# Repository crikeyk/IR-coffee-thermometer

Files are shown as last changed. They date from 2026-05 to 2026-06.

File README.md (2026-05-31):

# IR-coffee-thermometer







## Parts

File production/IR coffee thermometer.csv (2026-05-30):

Reference | Qty | Value | DNP | Exclude from BOM | Exclude from Board | Footprint | LCSC
AE2 | 1 | Antenna_Chip |  |  |  | Capacitor_SMD:C_1206_3216Metric | C127629
C1,C3,C4,C5 | 4 | 10uF |  |  |  | PCM_JLCPCB:C_0603 | C96446
C2 | 1 | 1uF |  |  |  | PCM_JLCPCB:C_0402 | C52923
C6,C15,C19,C20,C21,C22 | 6 | 100nF |  |  |  | PCM_JLCPCB:C_0402 | C1525
C10,C11 | 2 | 12pF |  |  |  | PCM_JLCPCB:C_0402 | C1547
D1 | 1 | Green |  |  |  | PCM_JLCPCB:D_0805 | C2297
D2 | 1 | Red |  |  |  | PCM_JLCPCB:D_0805 | C84256
D3 | 1 | 1N4001W |  |  |  | PCM_JLCPCB:D_SOD-123FL | C18199085
FB1 | 1 |  |  |  |  | PCM_JLCPCB:FB_0805 | C1015
J2 | 1 | USB_C_Receptacle_USB2.0_16P |  |  |  | MyLib:USB_C_Receptacle_HRO_TYPE-C-31-M-12 | C165948
Q2 | 1 | HL2305 |  |  |  | PCM_JLCPCB:Q_SOT-23 | C28646261
Q3 | 1 | HJ8205 |  |  |  | PCM_JLCPCB:SOT-23-6_L2.9-W1.6-P0.95-LS2.8-BR | C20069150
R1 | 1 | 510Ω |  |  |  | PCM_JLCPCB:R_0402 | C25123
R2,R16,R17 | 3 | 22Ω |  |  |  | PCM_JLCPCB:R_0402 | C25092
R3,R4 | 2 | 4.7kΩ |  |  |  | PCM_JLCPCB:R_0402 | C25900
R5,R8,R11,R12,R13,R23,R24 | 7 | 10kΩ |  |  |  | PCM_JLCPCB:R_0402 | C25744
R6 | 1 | 330Ω |  |  |  | PCM_JLCPCB:R_0402 | C25104
R7 | 1 | 2kΩ |  |  |  | PCM_JLCPCB:R_0402 | C4109
R9 | 1 | 0Ω | DNP |  |  | PCM_JLCPCB:R_0402 | C17168
R10 | 1 | 1kΩ |  |  |  | PCM_JLCPCB:R_0402 | C11702
R14,R15 | 2 | 5.1kΩ |  |  |  | PCM_JLCPCB:R_0402 | C25905
R18,R19,R20 | 3 | 0Ω |  |  |  | PCM_JLCPCB:R_0402 | C17168
R21,R22 | 2 | 470Ω |  |  |  | PCM_JLCPCB:R_0402 | C25117
U1 | 1 | ESP32-C3FH4 |  |  |  | PCM_JLCPCB:QFN-32-1EP_5x5mm_P0.5mm_EP3.7x3.7mm_ThermalVias | C2858491
U3 | 1 | DW01A |  |  |  | Package_TO_SOT_SMD:SOT-23-6 | C18164398
U4 | 1 | TP4057 |  |  |  | PCM_JLCPCB:SOT-23-6_L2.9-W1.6-P0.95-LS2.8-BL | C12044
U5 | 1 | MCP1700x-330xxTT |  |  |  | Package_TO_SOT_SMD:SOT-23 | C39051
X1 | 1 | 40MHz, 15pF |  |  |  | PCM_JLCPCB:OSC-SMD_4P-L3.2-W2.5-BL_SIT8008BI | C9010

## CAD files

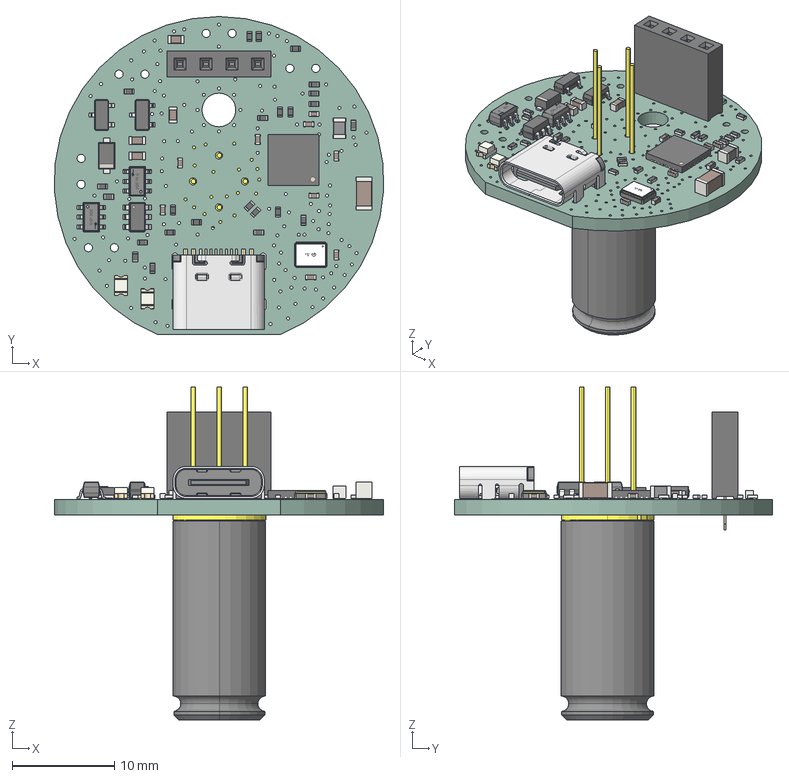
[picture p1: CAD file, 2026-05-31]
IR_coffee_thermometer_no_screen.step
32.3 x 31.2 x 32.6 mm
D_SOD_123F
LED_0805_2012Metric_Castellated x 2
R_0402_1005Metric x 24
C_0402_1005Metric x 9
SOT-23-6
C_0603_1608Metric x 4
PinSocket_1x04_P2.54mm_Vertical
C_1206_3216Metric
L_0805_2012Metric
SOT-23-6_L2.9-W1.6-H1.5-LS2.8-P0.95 x 2
OSC-SMD_4P-L3.2-W2.5-CJ13-320001210A20
ConPins
PcbPins
Mold
Frame
SOT-23
QFN-32-1EP_5x5mm_Pitch0.5mm
SOT_23
MLX90614xCI
IR coffee thermometer_PCB

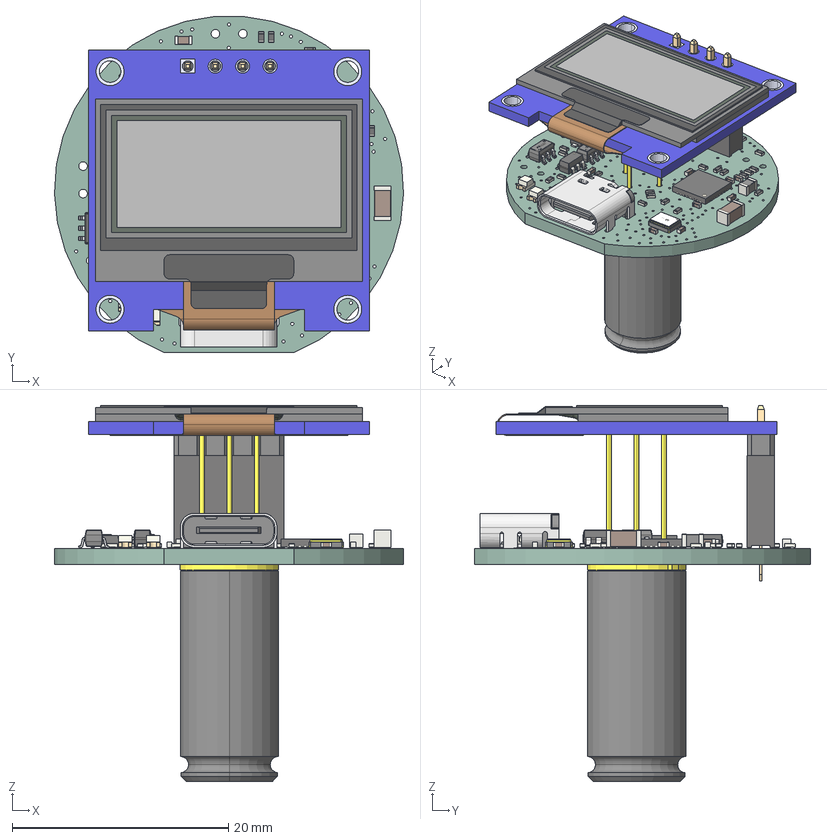
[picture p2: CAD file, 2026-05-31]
IR_coffee_thermometer.step
32.3 x 31.1 x 34.8 mm
D_SOD_123F
LED_0805_2012Metric_Castellated x 2
R_0402_1005Metric x 24
C_0402_1005Metric x 9
SOT-23-6
C_0603_1608Metric x 4
PinSocket_1x04_P2.54mm_Vertical
C_1206_3216Metric
L_0805_2012Metric
SOT-23-6_L2.9-W1.6-H1.5-LS2.8-P0.95 x 2
OSC-SMD_4P-L3.2-W2.5-CJ13-320001210A20
ConPins
PcbPins
Mold
Frame
DM-OLED096-636_Module
DM-OLED096-636_Panel
SOT-23
QFN-32-1EP_5x5mm_Pitch0.5mm
SOT_23
MLX90614xCI
IR coffee thermometer_PCB

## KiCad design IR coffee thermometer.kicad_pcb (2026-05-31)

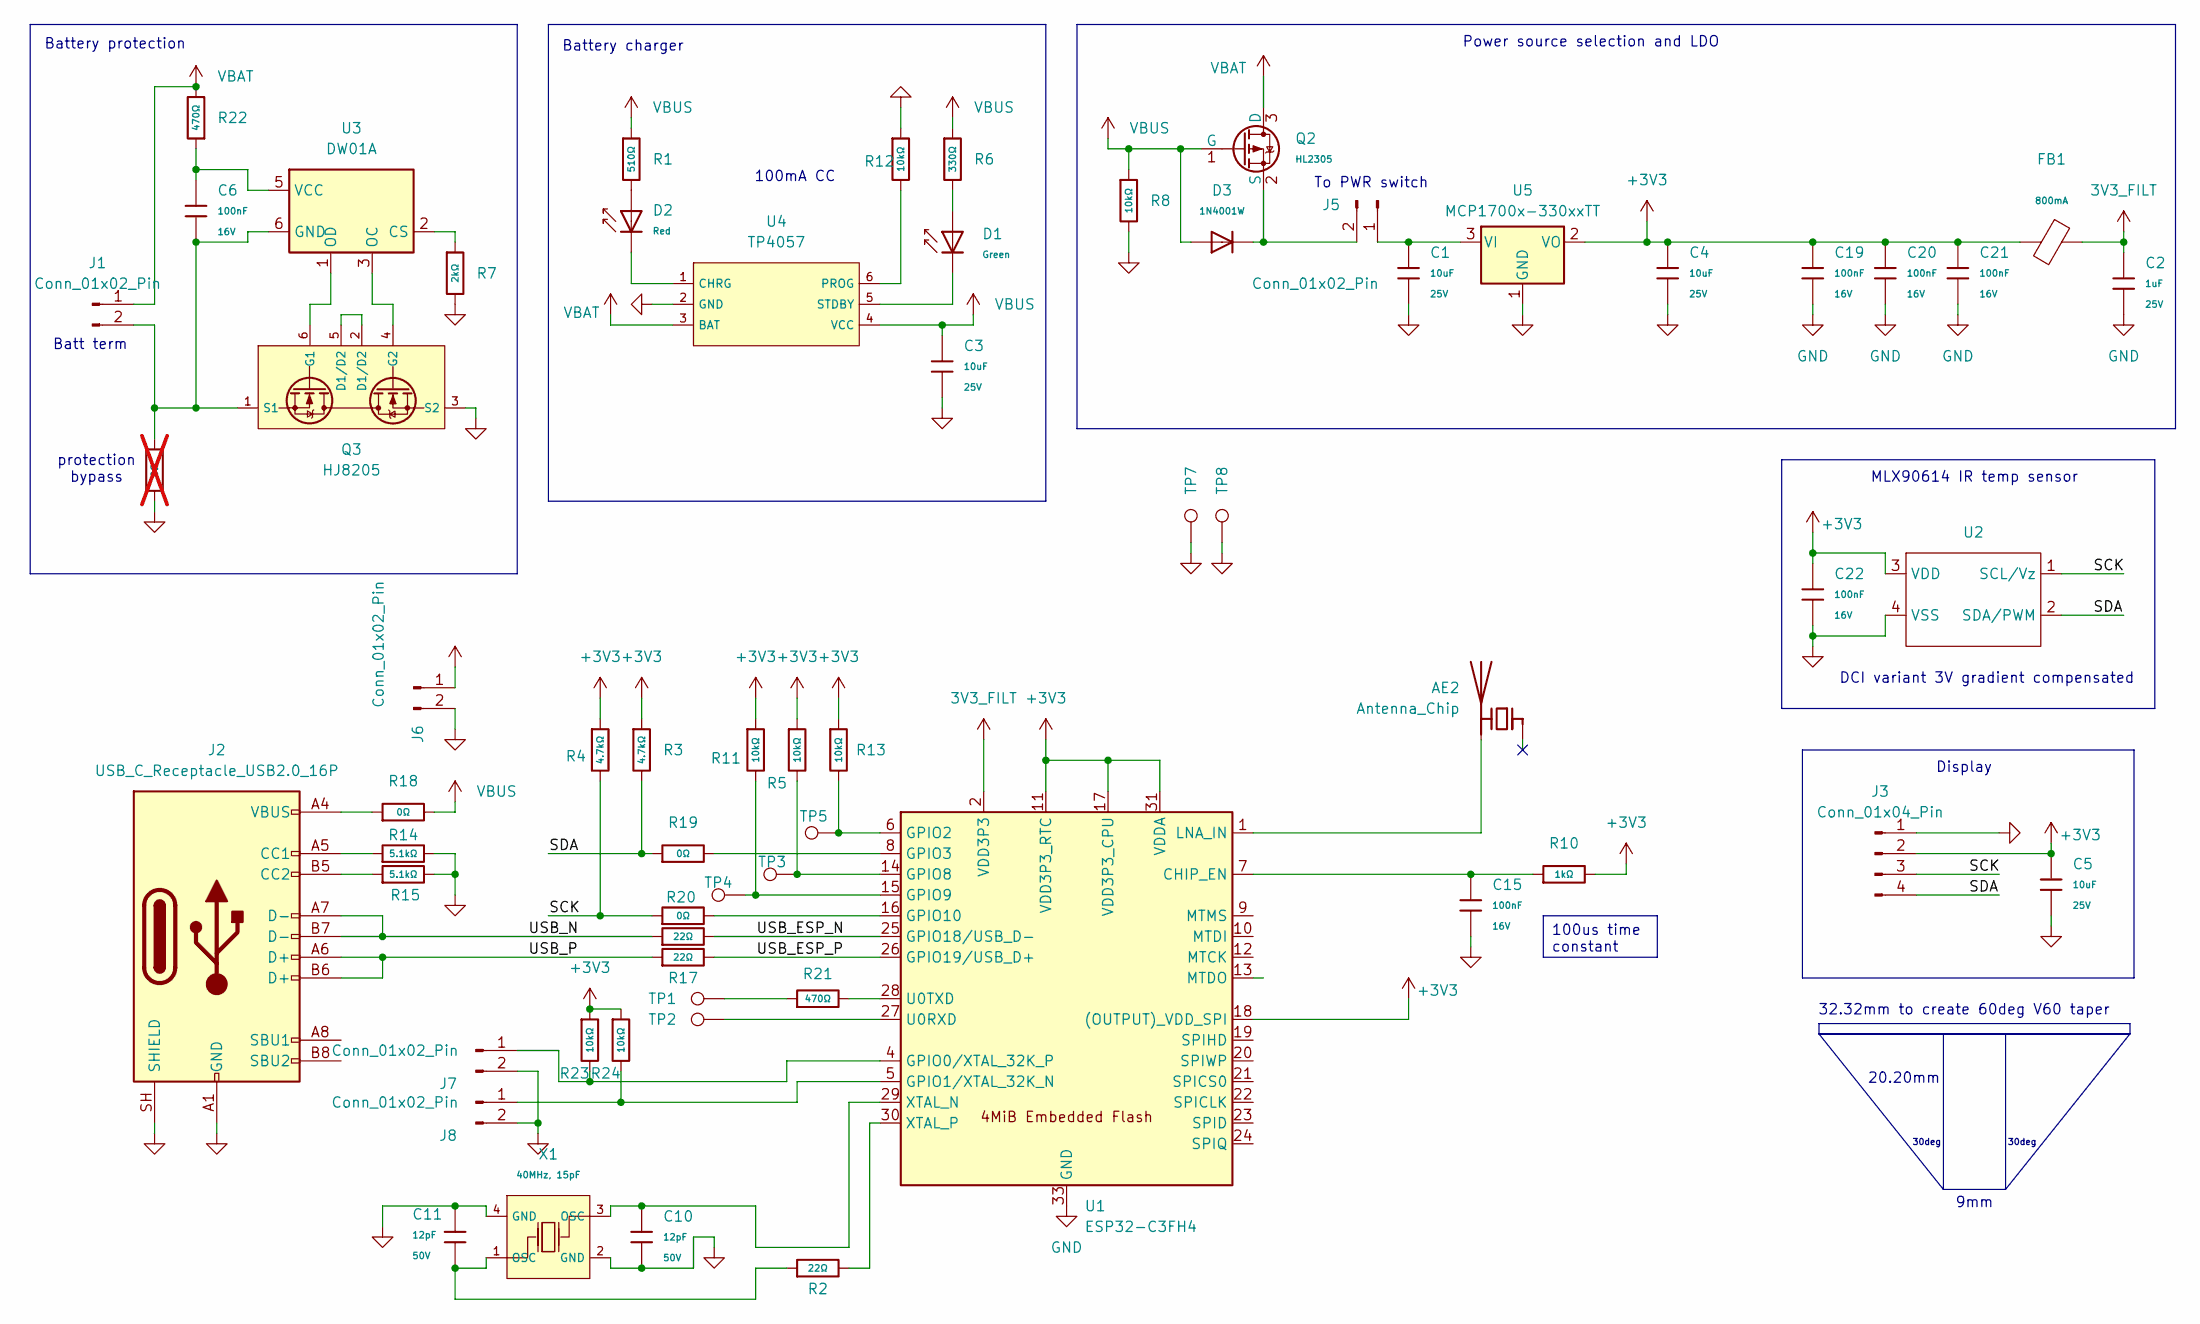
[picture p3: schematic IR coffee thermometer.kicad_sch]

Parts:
AE2: Antenna_Chip; C_1206_3216Metric; LCSC C127629
C1, C3, C4, C5: 10uF; C_0603; Voltage Rated 25V; Tolerance ±20%; Part CL10A106MA8NRNC; LCSC C96446
C2: 1uF; C_0402; Voltage Rated 25V; Tolerance ±10%; Part CL05A105KA5NQNC; LCSC C52923
C6, C15, C19, C20, C21, C22: 100nF; C_0402; Voltage Rated 16V; Tolerance ±10%; Part CL05B104KO5NNNC; LCSC C1525
C10, C11: 12pF; C_0402; Voltage Rated 50V; Tolerance ±5%; Part 0402CG120J500NT; LCSC C1547
D1: Green; D_0805; Part KT-0805G; LCSC C2297
D2: Red; D_0805; Forward Voltage (VF) 1.6V~2.6V; Part NCD0805R1; LCSC C84256
D3: 1N4001W; D_SOD-123FL; Voltage - Forward(Vf@If) 1V@1.0A; Voltage - DC Reverse(Vr) 50V; Part 1N4001W; LCSC C18199085
FB1: FB_0805; Current Rating 800mA; Tolerance ±25%; Part GZ2012D101TF; LCSC C1015
J1, J5, J6, J7, J8: Conn_01x02_Pin; TestPoint_2Pads_Pitch2.54mm_Drill0.8mm
J2: USB_C_Receptacle_USB2.0_16P; USB_C_Receptacle_HRO_TYPE-C-31-M-12; LCSC C165948
J3: Conn_01x04_Pin; PinSocket_1x04_P2.54mm_Vertical; LCSC C2718488
Q2: HL2305; Q_SOT-23; Part HL2305; LCSC C28646261
Q3: HJ8205; SOT-23-6_L2.9-W1.6-P0.95-LS2.8-BR; Part HJ8205; LCSC C20069150
R1: 510Ω; R_0402; Overload Voltage (Max) 50V; Tolerance ±1%; Part 0402WGF5100TCE; LCSC C25123
R2, R16, R17: 22Ω; R_0402; Overload Voltage (Max) 50V; Tolerance ±1%; Part 0402WGF220JTCE; LCSC C25092
R3, R4: 4.7kΩ; R_0402; Overload Voltage (Max) 50V; Tolerance ±1%; Part 0402WGF4701TCE; LCSC C25900
R5, R8, R11, R12, R13, R23, R24: 10kΩ; R_0402; Overload Voltage (Max) 50V; Tolerance ±1%; Part 0402WGF1002TCE; LCSC C25744
R6: 330Ω; R_0402; Overload Voltage (Max) 50V; Tolerance ±1%; Part 0402WGF3300TCE; LCSC C25104
R7: 2kΩ; R_0402; Overload Voltage (Max) 50V; Tolerance ±1%; Part 0402WGF2001TCE; LCSC C4109
R9: 0Ω; R_0402; Overload Voltage (Max) 50V; Tolerance ±1%; Part 0402WGF0000TCE; LCSC C17168; not fitted
R10: 1kΩ; R_0402; Overload Voltage (Max) 50V; Tolerance ±1%; Part 0402WGF1001TCE; LCSC C11702
R14, R15: 5.1kΩ; R_0402; Overload Voltage (Max) 50V; Tolerance ±1%; Part 0402WGF5101TCE; LCSC C25905
R18, R19, R20: 0Ω; R_0402; Overload Voltage (Max) 50V; Tolerance ±1%; Part 0402WGF0000TCE; LCSC C17168
R21, R22: 470Ω; R_0402; Overload Voltage (Max) 50V; Tolerance ±1%; Part 0402WGF4700TCE; LCSC C25117
TP1, TP2, TP3, TP4, TP5, TP7, TP8: TestPoint; TestPoint_Pad_D1.0mm
U1: ESP32-C3FH4; QFN-32-1EP_5x5mm_P0.5mm_EP3.7x3.7mm_ThermalVias; LCSC C2858491
U2: MLX90614
U3: DW01A; SOT-23-6; LCSC C18164398
U4: TP4057; SOT-23-6_L2.9-W1.6-P0.95-LS2.8-BL; Part TP4057-42-SOT26-R; LCSC C12044
U5: MCP1700x-330xxTT; SOT-23; LCSC C39051
X1: 40MHz, 15pF; OSC-SMD_4P-L3.2-W2.5-BL_SIT8008BI; PartID X322540MPB4SI; LCSC C9010

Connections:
3V3_FILT: C2.1, FB1.1, U1.2 (VDD3P3), U1.3 (VDD3P3)
+3V3: C4.1, C5.1, C19.1, C20.1, C21.1, C22.1, FB1.2, J3.2, R3.1, R4.1, R5.1, R10.2, R11.1, R13.1, R23.1, R24.1, U1.11 (VDD3P3_RTC), U1.17 (VDD3P3_CPU), U1.18 ((OUTPUT)_VDD_SPI), U1.31 (VDDA), U1.32 (VDDA), U2.3 (VDD), U5.2 (VO)
/SCK: J3.3, R4.2, R20.1, U2.1 (SCL/Vz)
/SDA: J3.4, R3.2, R19.1, U2.2 (SDA/PWM)
/USB_ESP_N: R16.2, U1.25 (GPIO18/USB_D-)
/USB_ESP_P: R17.2, U1.26 (GPIO19/USB_D+)
/USB_N: J2.A7 (D-), J2.B7 (D-), R16.1
/USB_P: J2.A6 (D+), J2.B6 (D+), R17.1
GND: C1.2, C2.2, C3.2, C4.2, C5.2, C10.2, C11.2, C15.2, C19.2, C20.2, C21.2, C22.2, J2.A1 (GND), J2.A12 (GND), J2.B1 (GND), J2.B12 (GND), J2.SH (SHIELD), J3.1, J6.2, J7.2, J8.2, Q3.3 (S2), R7.2, R8.2, R9.2, R12.1, R14.2, R15.2, TP7.1 (1_1), TP8.1 (1_1), U1.33 (GND), U2.4 (VSS), U4.2 (GND), U5.1 (GND), X1.2 (GND), X1.4 (GND)
unnamed: AE2.2 (PCB_Trace_2), U1.1 (LNA_IN)
unnamed: C11.1, R2.1, X1.1 (OSC)
unnamed: D1.2, R6.2
unnamed: D2.2, R1.2
unnamed: C6.2, J1.2, Q3.1 (S1), R9.1, U3.6 (GND)
unnamed: J2.A5 (CC1), R14.1
unnamed: J2.B5 (CC2), R15.1
unnamed: J2.A4 (VBUS), J2.A9 (VBUS), J2.B4 (VBUS), J2.B9 (VBUS), R18.1
unnamed: C1.1, J5.1, U5.3 (VI)
unnamed: D3.1, J5.2, Q2.2 (S)
unnamed: J7.1, R23.2, U1.4 (GPIO0/XTAL_32K_P)
unnamed: J8.1, R24.2, U1.5 (GPIO1/XTAL_32K_N)
unnamed: Q3.2 (D1/D2), Q3.5 (D1/D2)
unnamed: Q3.6 (G1), U3.1 (OD)
unnamed: Q3.4 (G2), U3.3 (OC)
unnamed: R21.1, TP1.1 (1_1)
unnamed: C15.1, R10.1, U1.7 (CHIP_EN)
unnamed 26: R13.2, TP5.1, U1.6 (GPIO2); also elsewhere on the board
unnamed: R19.2, U1.8 (GPIO3)
unnamed 28: R5.2, TP3.1, U1.14 (GPIO8); also elsewhere on the board
unnamed 29: R11.2, TP4.1, U1.15 (GPIO9); also elsewhere on the board
unnamed: R20.2, U1.16 (GPIO10)
unnamed: TP2.1 (1_1), U1.27 (U0RXD)
unnamed: R21.2, U1.28 (U0TXD)
unnamed: C10.1, U1.29 (XTAL_N), X1.3 (OSC)
unnamed: R2.2, U1.30 (XTAL_P)
unnamed: R7.1, U3.2 (CS)
unnamed: C6.1, R22.1, U3.5 (VCC)
unnamed: D2.1, U4.1 (CHRG)
unnamed: R12.2, U4.6 (PROG)
unnamed: D1.1, U4.5 (STDBY)
VBAT: J1.1, Q2.3 (D), R22.2, U4.3 (BAT)
VBUS: C3.1, D3.2, J6.1, Q2.1 (G), R1.1, R6.1, R8.1, R18.2, U4.4 (VCC)

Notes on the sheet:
30deg
DCI variant 3V gradient compensated
9mm
20.20mm
Power source selection and LDO
To PWR switch
100mA CC
Display
MLX90614 IR temp sensor
32.32mm to create 60deg V60 taper
Battery charger
protection bypass
Batt term
Battery protection
100us time constant

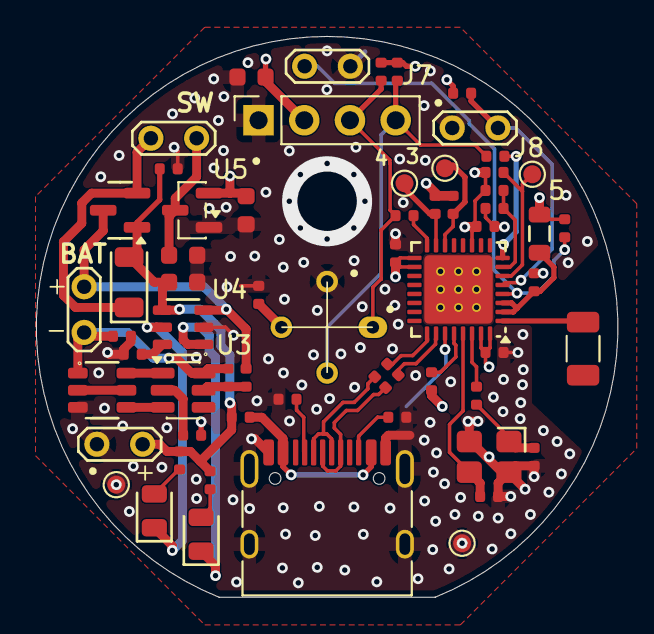
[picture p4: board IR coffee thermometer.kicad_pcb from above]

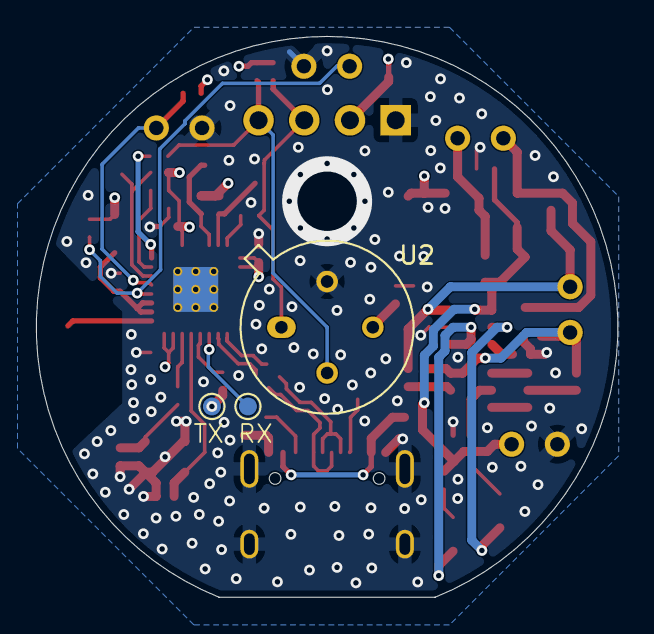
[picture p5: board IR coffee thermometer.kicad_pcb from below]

Board: 4 copper layers, 32.3 x 31.2 mm, 64 parts (3 on the bottom side), 42 nets.

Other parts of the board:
3, 4, 5: TestPoint; TestPoint_Pad_D1.0mm

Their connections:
unnamed 26: 5.1 (1_1); also elsewhere on the board
unnamed 28: 3.1 (1_1); also elsewhere on the board
unnamed 29: 4.1 (1_1); also elsewhere on the board

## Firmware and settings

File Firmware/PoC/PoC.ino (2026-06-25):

#include <Wire.h>
#include <Adafruit_GFX.h>
#include <Adafruit_SSD1306.h>
#include <Adafruit_MLX90614.h>
#include <WiFi.h>
#include <WebServer.h>
#include <DNSServer.h>
#include <Preferences.h>

// ── Pin / display config ─────────────────────────────────────────
#define SCREEN_WIDTH  128
#define SCREEN_HEIGHT 64
#define OLED_RESET    -1
#define OLED_ADDRESS  0x3C
#define PIN_SCK       10
#define PIN_SDA        3

// ── WiFi config ──────────────────────────────────────────────────
#define AP_SSID       "IR-Thermometer"

// ── Quick-boot detection ─────────────────────────────────────────
// If the device was on for less than QUICKBOOT_WINDOW_MS on the previous
// boot, we treat this boot as the "second boot" and enable WiFi.
#define QUICKBOOT_WINDOW_MS  1000   // 1 seconds

// ── OLED graph config ────────────────────────────────────────────
// Graph occupies the bottom portion of the display.
// Top area: current temp reading (large text).
#define GRAPH_TOP     36            // y pixel where graph starts
#define GRAPH_HEIGHT  (SCREEN_HEIGHT - GRAPH_TOP)   // 28 px
#define GRAPH_WIDTH   SCREEN_WIDTH                  // 128 samples
#define GRAPH_AUTOSCALE_MARGIN_C  1.0   // pad min/max by this many °C

// ── Objects ──────────────────────────────────────────────────────
Adafruit_SSD1306 display(SCREEN_WIDTH, SCREEN_HEIGHT, &Wire, OLED_RESET);
Adafruit_MLX90614 mlx;
WebServer server(80);
DNSServer dnsServer;
Preferences prefs;

// ── Shared state ─────────────────────────────────────────────────
struct TempData {
  double ambient;
  double object;
  bool   valid;
};
TempData tempData = { 0, 0, false };
SemaphoreHandle_t tempMutex;

bool wifiEnabled = false;   // set in setup(), read-only after that

// ── Web page ─────────────────────────────────────────────────────
const char INDEX_HTML[] PROGMEM = R"rawliteral(
<!DOCTYPE html>
<html>
<head>
  <meta charset="utf-8">
  <meta name="viewport" content="width=device-width, initial-scale=1">
  <title>IR Thermometer</title>
  <style>
    *, *::before, *::after { box-sizing: border-box; margin: 0; padding: 0; }

    :root {
      --bg:        #0d0d0f;
      --surface:   #18181c;
      --border:    #2a2a32;
      --accent:    #f97316;
      --accent-lo: rgba(249,115,22,0.12);
      --cool:      #38bdf8;
      --text:      #f1f0ee;
      --muted:     #6b6b78;
      --label:     #9a9aa8;
    }

    body {
      font-family: 'SF Mono', 'Fira Code', 'Consolas', monospace;
      background: var(--bg);
      color: var(--text);
      min-height: 100vh;
      padding: 24px 16px 40px;
      display: flex;
      flex-direction: column;
      align-items: center;
      gap: 16px;
    }

    header {
      width: 100%;
      max-width: 560px;
      display: flex;
      align-items: baseline;
      gap: 10px;
      padding-bottom: 12px;
      border-bottom: 1px solid var(--border);
    }
    header h1 {
      font-size: 0.7rem;
      letter-spacing: 0.18em;
      text-transform: uppercase;
      color: var(--muted);
      font-weight: 400;
    }
    .live-dot {
      width: 6px; height: 6px;
      border-radius: 50%;
      background: #4ade80;
      flex-shrink: 0;
      animation: blink 2s ease-in-out infinite;
    }
    @keyframes blink { 0%,100%{opacity:1} 50%{opacity:.2} }

    /* ── Big readings row ── */
    .readings {
      width: 100%;
      max-width: 560px;
      display: grid;
      grid-template-columns: 1fr 1fr;
      gap: 12px;
    }
    .card {
      background: var(--surface);
      border: 1px solid var(--border);
      border-radius: 12px;
      padding: 18px 20px 14px;
    }
    .card.primary {
      border-color: var(--accent);
      background: linear-gradient(145deg, #1c1510 0%, var(--surface) 100%);
    }
    .card-label {
      font-size: 0.6rem;
      letter-spacing: 0.2em;
      text-transform: uppercase;
      color: var(--label);
      margin-bottom: 6px;
    }
    .card-value {
      font-size: 2.8rem;
      font-weight: 300;
      letter-spacing: -0.03em;
      line-height: 1;
      color: var(--text);
    }
    .card.primary .card-value { color: var(--accent); }
    .card-unit {
      font-size: 0.9rem;
      color: var(--muted);
      margin-left: 2px;
    }
    .delta-row {
      width: 100%;
      max-width: 560px;
      background: var(--surface);
      border: 1px solid var(--border);
      border-radius: 12px;
      padding: 12px 20px;
      display: flex;
      align-items: center;
      justify-content: space-between;
    }
    .delta-row .card-label { margin: 0; }
    .delta-val {
      font-size: 1.4rem;
      font-weight: 300;
    }
    .pos { color: var(--accent); }
    .neg { color: var(--cool);  }

    /* ── Chart ── */
    .chart-wrap {
      width: 100%;
      max-width: 560px;
      background: var(--surface);
      border: 1px solid var(--border);
      border-radius: 12px;
      padding: 16px 20px 12px;
    }
    .chart-title {
      font-size: 0.6rem;
      letter-spacing: 0.18em;
      text-transform: uppercase;
      color: var(--muted);
      margin-bottom: 12px;
    }
    canvas {
      width: 100%;
      height: 180px;
      display: block;
    }

    .footer {
      font-size: 0.6rem;
      color: var(--muted);
      letter-spacing: 0.08em;
    }
  </style>
</head>
<body>

  <header>
    <div class="live-dot"></div>
    <h1>IR Thermometer</h1>
  </header>

  <div class="readings">
    <div class="card primary">
      <div class="card-label">Object</div>
      <div class="card-value" id="obj">--<span class="card-unit">°C</span></div>
    </div>
    <div class="card">
      <div class="card-label">Ambient</div>
      <div class="card-value" id="amb">--<span class="card-unit">°C</span></div>
    </div>
  </div>

  <div class="delta-row">
    <div class="card-label">Delta</div>
    <div class="delta-val" id="delta">-- °C</div>
  </div>

  <div class="chart-wrap">
    <div class="chart-title">History · last 60 s</div>
    <canvas id="chart"></canvas>
  </div>

  <div class="footer" id="status">connecting…</div>

<script>
  // ── History buffers (60 points, one per second) ───────────────
  const MAX_PTS = 60;
  const objHist = [];
  const ambHist = [];

  // ── Canvas chart ──────────────────────────────────────────────
  const canvas = document.getElementById('chart');
  const ctx    = canvas.getContext('2d');

  function resizeCanvas() {
    canvas.width  = canvas.offsetWidth  * devicePixelRatio;
    canvas.height = canvas.offsetHeight * devicePixelRatio;
  }
  window.addEventListener('resize', resizeCanvas);
  resizeCanvas();

  function drawChart() {
    const W = canvas.width;
    const H = canvas.height;
    ctx.clearRect(0, 0, W, H);

    if (objHist.length < 2) return;

    const combined = [...objHist, ...ambHist];
    let lo = Math.min(...combined);
    let hi = Math.max(...combined);
    if (hi - lo < 2) { lo -= 1; hi += 1; }   // minimum span
    const pad = (hi - lo) * 0.1;
    lo -= pad; hi += pad;

    const scaleY = v => H - ((v - lo) / (hi - lo)) * H;
    const scaleX = i => (i / (MAX_PTS - 1)) * W;

    // Grid lines (3)
    ctx.strokeStyle = 'rgba(255,255,255,0.06)';
    ctx.lineWidth = 1 * devicePixelRatio;
    [0.25, 0.5, 0.75].forEach(f => {
      const y = H * f;
      ctx.beginPath();
      ctx.moveTo(0, y);
      ctx.lineTo(W, y);
      ctx.stroke();

      // y-axis label
      const temp = lo + (hi - lo) * (1 - f);
      ctx.fillStyle = 'rgba(155,155,168,0.7)';
      ctx.font = `${10 * devicePixelRatio}px monospace`;
      ctx.fillText(temp.toFixed(1), 4 * devicePixelRatio, y - 3 * devicePixelRatio);
    });

    function plotLine(data, color, fillColor) {
      if (data.length < 2) return;
      const pts = data.map((v, i) => ({
        x: scaleX(i + (MAX_PTS - data.length)),
        y: scaleY(v)
      }));

      // Fill
      ctx.beginPath();
      ctx.moveTo(pts[0].x, H);
      pts.forEach(p => ctx.lineTo(p.x, p.y));
      ctx.lineTo(pts[pts.length - 1].x, H);
      ctx.closePath();
      ctx.fillStyle = fillColor;
      ctx.fill();

      // Line
      ctx.beginPath();
      pts.forEach((p, i) => i === 0 ? ctx.moveTo(p.x, p.y) : ctx.lineTo(p.x, p.y));
      ctx.strokeStyle = color;
      ctx.lineWidth = 2 * devicePixelRatio;
      ctx.lineJoin = 'round';
      ctx.stroke();
    }

    // Ambient behind, object in front
    plotLine(ambHist, '#38bdf8', 'rgba(56,189,248,0.07)');
    plotLine(objHist, '#f97316', 'rgba(249,115,22,0.12)');

    // Legend
    const lx = W - 80 * devicePixelRatio;
    const ly = 10 * devicePixelRatio;
    const fs = 9 * devicePixelRatio;
    ctx.font = `${fs}px monospace`;
    [[`#f97316`, 'Object'], [`#38bdf8`, 'Ambient']].forEach(([c, label], i) => {
      const y = ly + i * 14 * devicePixelRatio;
      ctx.fillStyle = c;
      ctx.fillRect(lx, y, 10 * devicePixelRatio, 2 * devicePixelRatio);
      ctx.fillStyle = 'rgba(155,155,168,0.9)';
      ctx.fillText(label, lx + 14 * devicePixelRatio, y + fs * 0.8);
    });
  }

  // ── DOM refs ──────────────────────────────────────────────────
  const elObj    = document.getElementById('obj');
  const elAmb    = document.getElementById('amb');
  const elDelta  = document.getElementById('delta');
  const elStatus = document.getElementById('status');

  function poll() {
    fetch('/data')
      .then(r => r.json())
      .then(d => {
        elObj.innerHTML  = `${d.object.toFixed(2)}<span class="card-unit">°C</span>`;
        elAmb.innerHTML  = `${d.ambient.toFixed(2)}<span class="card-unit">°C</span>`;

        const diff = d.object - d.ambient;
        const sign = diff >= 0 ? '+' : '';
        const cls  = diff >= 0 ? 'pos' : 'neg';
        elDelta.innerHTML = `<span class="${cls}">${sign}${diff.toFixed(2)} °C</span>`;

        objHist.push(d.object);
        ambHist.push(d.ambient);
        if (objHist.length > MAX_PTS) objHist.shift();
        if (ambHist.length > MAX_PTS) ambHist.shift();

        drawChart();
        elStatus.textContent = `updated ${new Date().toLocaleTimeString()}`;
      })
      .catch(() => { elStatus.textContent = 'connection lost — retrying…'; });
  }

  poll();
  setInterval(poll, 1000);
</script>
</body>
</html>
)rawliteral";

// ── Handlers ─────────────────────────────────────────────────────
void handleRoot() {
  server.send_P(200, "text/html", INDEX_HTML);
}

void handleData() {
  TempData snap;
  if (xSemaphoreTake(tempMutex, pdMS_TO_TICKS(50)) == pdTRUE) {
    snap = tempData;
    xSemaphoreGive(tempMutex);
  }
  char buf[72];
  snprintf(buf, sizeof(buf),
           "{\"ambient\":%.2f,\"object\":%.2f,\"valid\":%s}",
           snap.ambient, snap.object, snap.valid ? "true" : "false");
  server.send(200, "application/json", buf);
}

void handleCaptive() {
  server.sendHeader("Location", "http://192.168.4.1/", true);
  server.send(302, "text/plain", "");
}

// ── OLED rolling graph state ─────────────────────────────────────
static float  graphBuf[GRAPH_WIDTH];   // circular buffer of object temps
static int    graphHead  = 0;          // next write index
static int    graphCount = 0;          // how many valid samples
static float  graphMin   = 1e9f;
static float  graphMax   = -1e9f;

void graphPush(float val) {
  graphBuf[graphHead] = val;
  graphHead = (graphHead + 1) % GRAPH_WIDTH;
  if (graphCount < GRAPH_WIDTH) graphCount++;

  // Recompute min/max over entire buffer
  graphMin = 1e9f; graphMax = -1e9f;
  int start = (graphHead - graphCount + GRAPH_WIDTH) % GRAPH_WIDTH;
  for (int i = 0; i < graphCount; i++) {
    float v = graphBuf[(start + i) % GRAPH_WIDTH];
    if (v < graphMin) graphMin = v;
    if (v > graphMax) graphMax = v;
  }
}

// Draw the rolling graph into the lower portion of the display buffer.
// Call AFTER display.clearDisplay() and before display.display().
void drawOledGraph() {
  if (graphCount < 2) return;

  float lo = graphMin - GRAPH_AUTOSCALE_MARGIN_C;
  float hi = graphMax + GRAPH_AUTOSCALE_MARGIN_C;
  if (hi - lo < 1.0f) { lo -= 0.5f; hi += 0.5f; }

  int start = (graphHead - graphCount + GRAPH_WIDTH) % GRAPH_WIDTH;

  // Map count samples across SCREEN_WIDTH pixels
  int prevX = -1, prevY = -1;
  for (int px = 0; px < SCREEN_WIDTH; px++) {
    // which sample index corresponds to pixel px?
    int si = (int)((float)px / (SCREEN_WIDTH - 1) * (graphCount - 1) + 0.5f);
    float v = graphBuf[(start + si) % GRAPH_WIDTH];
    int py = GRAPH_TOP + GRAPH_HEIGHT - 1
             - (int)(((v - lo) / (hi - lo)) * (GRAPH_HEIGHT - 1));
    py = constrain(py, GRAPH_TOP, SCREEN_HEIGHT - 1);

    if (prevX >= 0) {
      display.drawLine(prevX, prevY, px, py, SSD1306_WHITE);
    }
    prevX = px; prevY = py;
  }

  // Y-axis labels (min / max) at right edge, tiny font
  display.setTextSize(1);
  display.setTextColor(SSD1306_WHITE);
  // max label top-right
  char buf[10];
  snprintf(buf, sizeof(buf), "%.1f", hi - GRAPH_AUTOSCALE_MARGIN_C);
  display.setCursor(SCREEN_WIDTH - 6 * strlen(buf), GRAPH_TOP);
  display.print(buf);
  // min label bottom-right
  snprintf(buf, sizeof(buf), "%.1f", lo + GRAPH_AUTOSCALE_MARGIN_C);
  display.setCursor(SCREEN_WIDTH - 6 * strlen(buf), SCREEN_HEIGHT - 8);
  display.print(buf);
}

// ── Task 1: Sensor ───────────────────────────────────────────────
void taskSensor(void* pvParameters) {
  for (;;) {
    double amb = mlx.readAmbientTempC();
    double obj = mlx.readObjectTempC();
    bool valid = (amb > -40 && amb < 125 && obj > -70 && obj < 380);

    if (valid) {
      if (xSemaphoreTake(tempMutex, pdMS_TO_TICKS(50)) == pdTRUE) {
        tempData.ambient = amb;
        tempData.object  = obj;
        tempData.valid   = true;
        xSemaphoreGive(tempMutex);
      }
      graphPush((float)obj);   // feed rolling graph (no mutex needed — only this task writes)
    }
    vTaskDelay(pdMS_TO_TICKS(200));
  }
}

// ── Task 2: Display ──────────────────────────────────────────────
void taskDisplay(void* pvParameters) {
  for (;;) {
    TempData snap;
    if (xSemaphoreTake(tempMutex, pdMS_TO_TICKS(50)) == pdTRUE) {
      snap = tempData;
      xSemaphoreGive(tempMutex);
    }

    display.clearDisplay();

    if (!snap.valid) {
      display.setTextSize(1);
      display.setTextColor(SSD1306_WHITE);
      display.setCursor(20, 28);
      display.println("Sensor error!");
      display.display();
      vTaskDelay(pdMS_TO_TICKS(200));
      continue;
    }

    // ── Top section: big object temp ─────────────────────────────
    // e.g. "36.75" in size-2 font (12px tall), centred vertically in top area
    display.setTextColor(SSD1306_WHITE);

    // Label "OBJ" tiny
    display.setTextSize(1);
    display.setCursor(0, 0);
    display.print("OBJ");

    // Value in size-2 font
    char valBuf[12];
    snprintf(valBuf, sizeof(valBuf), "%.2f", snap.object);
    display.setTextSize(2);
    // size-2 char is 12px tall; centre it in the GRAPH_TOP area (36px)
    int16_t ty = (GRAPH_TOP - 16) / 2;
    display.setCursor(22, ty);
    display.print(valBuf);

    // "C" unit small
    display.setTextSize(1);
    display.setCursor(22 + strlen(valBuf) * 12, ty + 4);
    display.print("C");

    // Divider
    display.drawFastHLine(0, GRAPH_TOP - 2, SCREEN_WIDTH, SSD1306_WHITE);

    // ── Lower section: rolling graph ─────────────────────────────
    drawOledGraph();

    display.display();
    vTaskDelay(pdMS_TO_TICKS(200));
  }
}

// ── Task 3: Web server + DNS ─────────────────────────────────────
void taskWebServer(void* pvParameters) {
  for (;;) {
    dnsServer.processNextRequest();
    server.handleClient();
    vTaskDelay(pdMS_TO_TICKS(2));
  }
}

// ── Task 4: Watchdog ─────────────────────────────────────────────
void taskWatchdog(void* pvParameters) {
  for (;;) {
    TempData snap;
    if (xSemaphoreTake(tempMutex, pdMS_TO_TICKS(50)) == pdTRUE) {
      snap = tempData;
      xSemaphoreGive(tempMutex);
    }
    Serial.printf("heap: %lu  amb: %.2f  obj: %.2f  valid: %d  wifi: %d\n",
                  esp_get_free_heap_size(),
                  snap.ambient, snap.object, snap.valid, wifiEnabled);
    vTaskDelay(pdMS_TO_TICKS(5000));
  }
}

// ── Quick-boot detection via NVS ─────────────────────────────────
// We write a flag at boot and clear it after QUICKBOOT_WINDOW_MS.
// If the flag is already set when we boot, the previous boot was short → enable WiFi.
bool detectQuickBoot() {
  prefs.begin("boot", false);
  bool flagSet = prefs.getBool("qb", false);
  // Immediately (re-)set the flag for this boot
  prefs.putBool("qb", true);
  prefs.end();
  return flagSet;   // true = previous boot was shorter than QUICKBOOT_WINDOW_MS
}

void clearQuickBootFlag() {
  prefs.begin("boot", false);
  prefs.putBool("qb", false);
  prefs.end();
}

// ── Setup ────────────────────────────────────────────────────────
void setup() {
  Serial.begin(115200);
  delay(200);
  Serial.println("\nESP32-C3 IR Thermometer boot");

  // ── Quick-boot detection ──────────────────────────────────────
  wifiEnabled = detectQuickBoot();
  Serial.printf("Quick-boot flag was %s → WiFi %s\n",
                wifiEnabled ? "SET" : "clear",
                wifiEnabled ? "ENABLED" : "disabled");

  // ── Hardware init ─────────────────────────────────────────────
  Wire.begin(PIN_SDA, PIN_SCK);
  Wire.setClock(400000);

  if (!display.begin(SSD1306_SWITCHCAPVCC, OLED_ADDRESS)) {
    Serial.println("HALTED: SSD1306 not found");
    for (;;) delay(2000);
  }
  Serial.println("Display OK");

  if (!mlx.begin()) {
    Serial.println("HALTED: MLX90614 not found");
    display.clearDisplay();
    display.setTextSize(1);
    display.setTextColor(SSD1306_WHITE);
    display.setCursor(10, 28);
    display.println("MLX90614 not found");
    display.display();
    for (;;) delay(2000);
  }
  Serial.println("MLX90614 OK");

  // First sensor read
  delay(200);
  tempData.ambient = mlx.readAmbientTempC();
  tempData.object  = mlx.readObjectTempC();
  tempData.valid   = (tempData.ambient > -40 && tempData.ambient < 125 &&
                      tempData.object  > -70 && tempData.object  < 380);

  // ── WiFi + web server (only if quick-boot detected) ───────────
  if (wifiEnabled) {
    clearQuickBootFlag();
    WiFi.softAP(AP_SSID);   // no password — open network
    IPAddress ip = WiFi.softAPIP();
    Serial.printf("AP: %s  IP: %s\n", AP_SSID, ip.toString().c_str());

    dnsServer.start(53, "*", ip);

    server.on("/",                           handleRoot);
    server.on("/data",                       handleData);
    server.on("/hotspot-detect.html",        handleCaptive);
    server.on("/library/test/success.html",  handleCaptive);
    server.on("/generate_204",               handleCaptive);
    server.on("/gen_204",                    handleCaptive);
    server.on("/connecttest.txt",            handleCaptive);
    server.on("/redirect",                   handleCaptive);
    server.on("/success.txt",               handleCaptive);
    server.on("/ncsi.txt",                   handleCaptive);
    server.onNotFound(handleCaptive);
    server.begin();
    Serial.println("Web server started");

    // Show WiFi info on OLED
    display.clearDisplay();
    display.setTextSize(1);
    display.setTextColor(SSD1306_WHITE);
    display.setCursor(0, 0);
    display.println("--- WiFi Enabled ---");
    display.println("");
    display.print("SSID: ");
    display.println(AP_SSID);
    // display.println("(no password)");
    display.println("");
    // display.println(ip.toString());
    display.display();
    delay(3000);
  } else {
    // Make sure WiFi radio is fully off to save power
    WiFi.mode(WIFI_OFF);
    Serial.println("WiFi off");
  }

  // ── Mutex + tasks ─────────────────────────────────────────────
  tempMutex = xSemaphoreCreateMutex();

  xTaskCreate(taskSensor,  "Sensor",  4096, NULL, 2, NULL);
  xTaskCreate(taskDisplay, "Display", 8192, NULL, 1, NULL);
  xTaskCreate(taskWatchdog,"Watchdog",4096, NULL, 1, NULL);

  if (wifiEnabled) {
    xTaskCreate(taskWebServer, "WebServer", 4096, NULL, 1, NULL);
  }

  // ── Clear the quick-boot flag after the safe window ───────────
  // Anything still running after QUICKBOOT_WINDOW_MS is a "normal" boot.
  // We do this in setup() on the main task — it's still within the Arduino
  // task, which persists. A small blocking delay here is fine because the
  // FreeRTOS tasks above are already running on their own stacks.
  delay(QUICKBOOT_WINDOW_MS);
  clearQuickBootFlag();
  Serial.println("Quick-boot flag cleared (normal boot confirmed)");
}

void loop() {
  vTaskDelay(pdMS_TO_TICKS(1000));
}

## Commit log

2026-05-21 basic layout
    [IR coffee thermometer.kicad_pcb, IR coffee thermometer.kicad_sch]
2026-05-22 schematic complete
    [IR coffee thermometer.kicad_pcb, IR coffee thermometer.kicad_sch, preliminary_3D_model.step]
2026-05-28 routing complete
    [IR coffee thermometer.kicad_pcb, IR coffee thermometer.kicad_sch]
2026-05-30 gerber out
    [IR coffee thermometer.csv, designators.csv, positions.csv]
2026-05-30 release for fab
    [IR coffee thermometer.kicad_pcb, IR coffee thermometer.kicad_sch]
2026-05-31 added step files
    [IR coffee thermometer.kicad_pcb, IR_coffee_thermometer.step, IR_coffee_thermometer_no_screen.step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]
2026-06-13 added Wifi only on reboot. added graphing
    [PoC.ino]
